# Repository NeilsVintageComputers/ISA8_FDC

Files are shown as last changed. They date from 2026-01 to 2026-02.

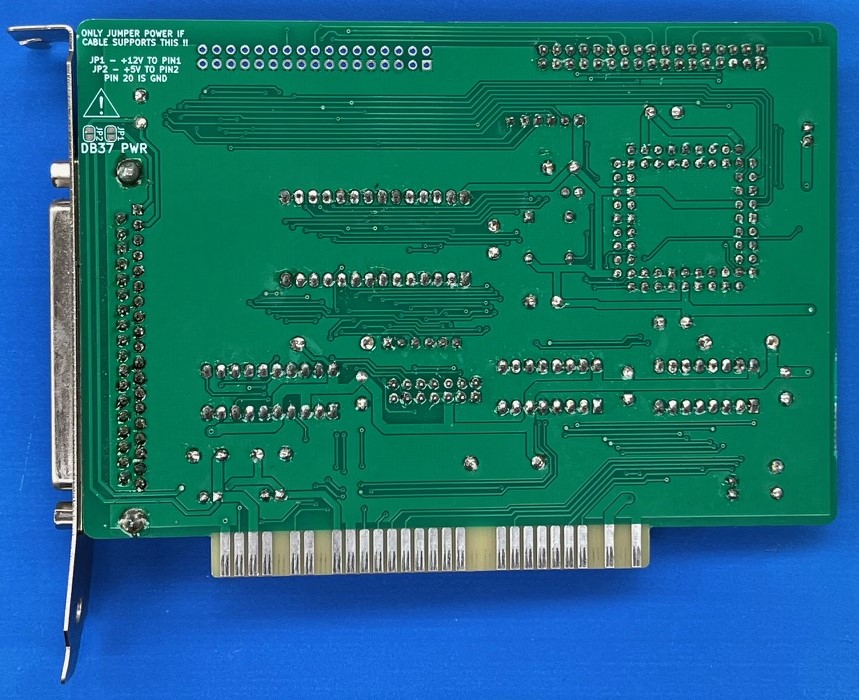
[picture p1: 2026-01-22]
ISA8_NFDCv1_4wayFDC/Photos/NFDCv1back.jpeg

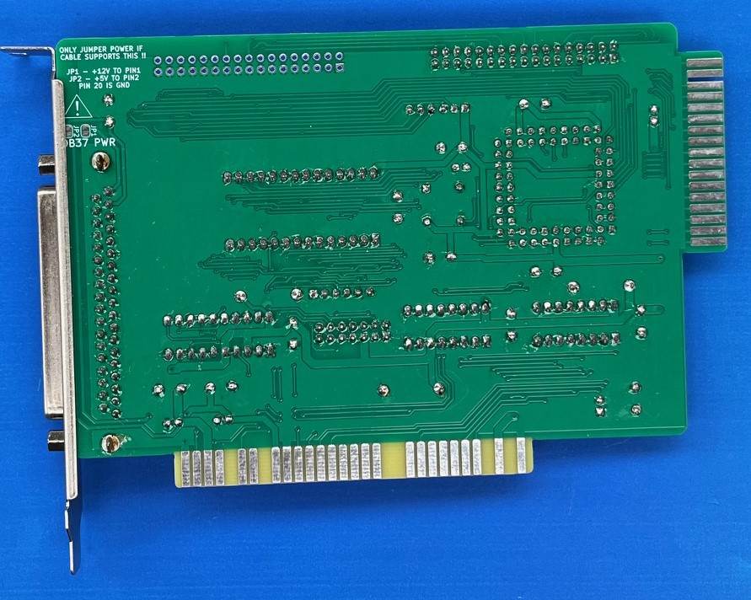
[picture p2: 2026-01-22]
ISA8_NFDCv2_4wayFDC/Photos/NFDCv2back.jpeg

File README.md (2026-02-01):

# ISA8_FDC

These FDCs are based on the Sergey Monster FDC, they use the Sergey FDC Bios V2.2, at the time of writing this was up to version 2.6 which should also work.

V1.0 is a 4-way FDC and has a external 37-pin connector option for the second pair of drives.

V2.0 supercedes V1.0, it is a 4-way FDC that has a internal PCB edge connector option for the first pair of drives and a external 37-pin connector option for the second pair of drives.

V1.0
NFDCv1

V2.0
NFDCv2

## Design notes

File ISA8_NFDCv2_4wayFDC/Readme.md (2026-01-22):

# NFDC V2.0 ISA8 FDC

This FDC is based on the Sergey Monster FDC, and uses the Sergey FDC Bios.

I have cut it down to a 4-way controller, similar to the NFDC V1.0, and added a edge connector option for the first pair of drives and a external 37-pin connector option using standard IBM pin connection that can be used for the second pair of drives.

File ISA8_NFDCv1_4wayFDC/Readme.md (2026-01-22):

# NFDC V1.0 ISA8 FDC

This FDC is based on the Sergey Monster FDC, and uses the Sergey FDC Bios.

I have cut it down to a 4-way controller and added a external 37-pin connector using standard IBM pin connection that can be used for the second pair of drives.

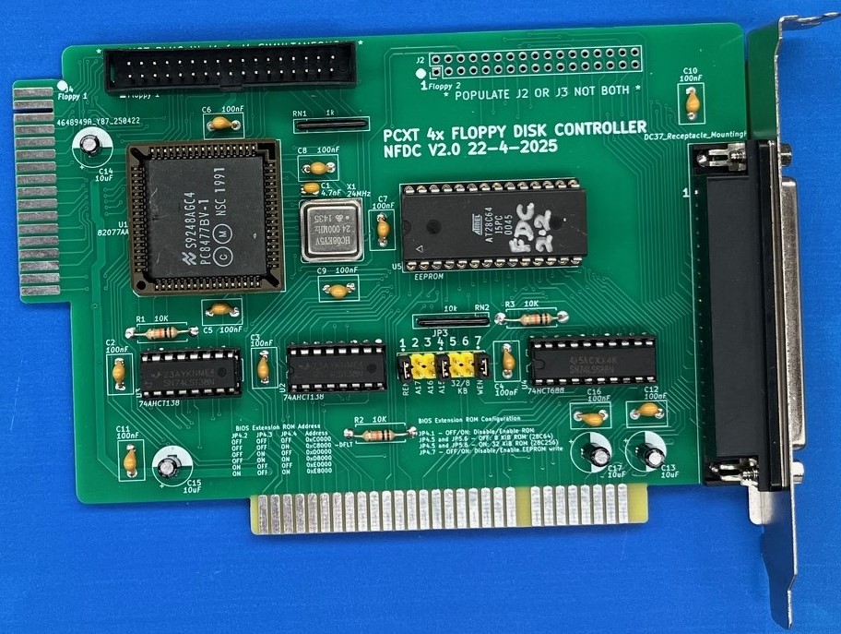
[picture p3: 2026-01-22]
ISA8_NFDCv2_4wayFDC/Photos/NFDCv2.jpeg

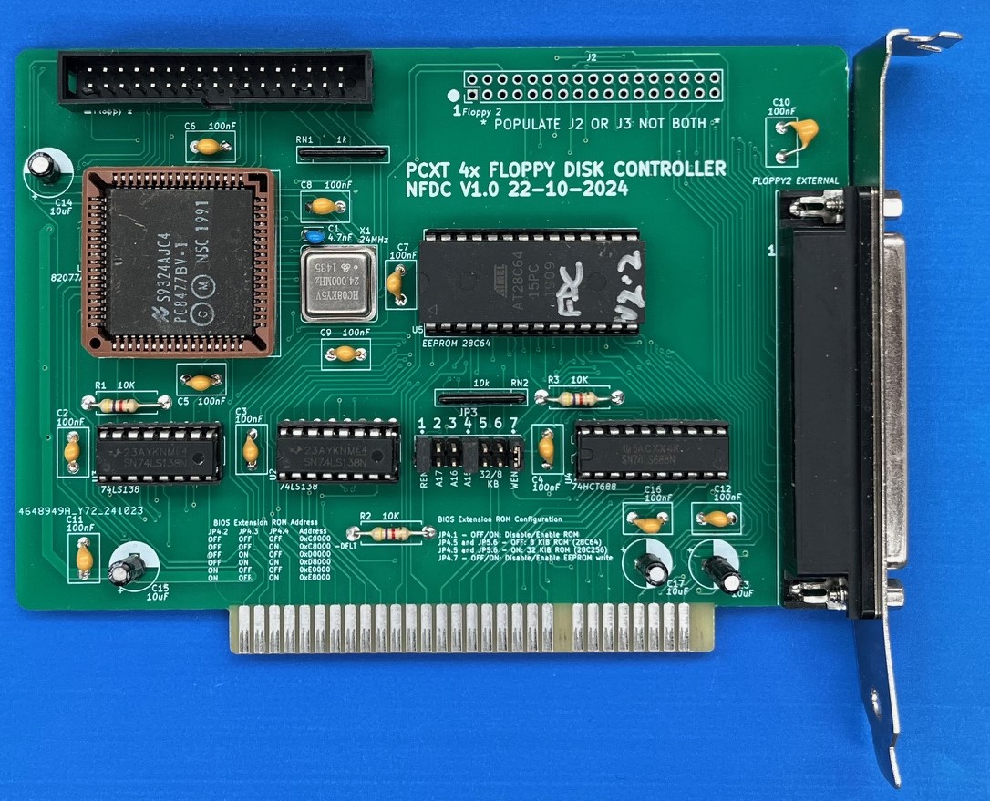
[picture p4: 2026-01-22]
ISA8_NFDCv1_4wayFDC/Photos/NFDCv1.jpeg

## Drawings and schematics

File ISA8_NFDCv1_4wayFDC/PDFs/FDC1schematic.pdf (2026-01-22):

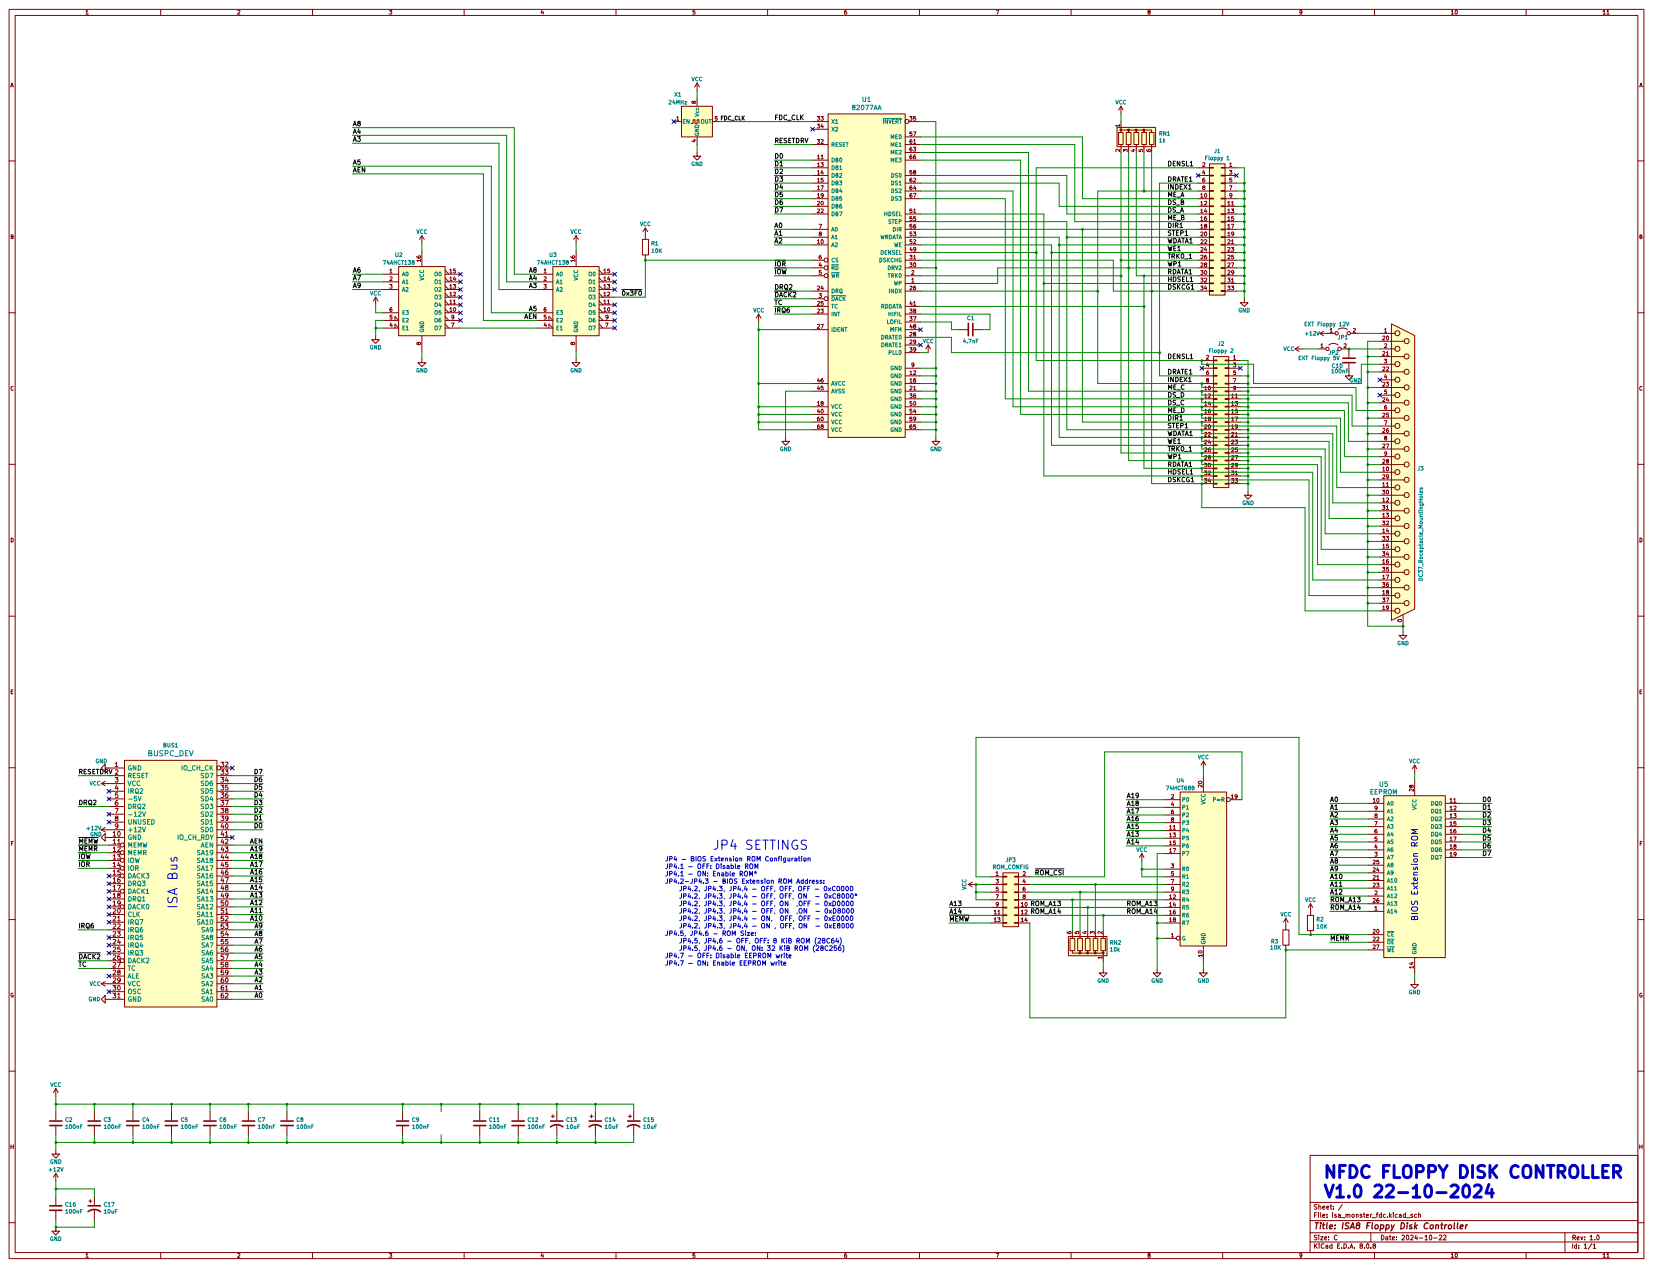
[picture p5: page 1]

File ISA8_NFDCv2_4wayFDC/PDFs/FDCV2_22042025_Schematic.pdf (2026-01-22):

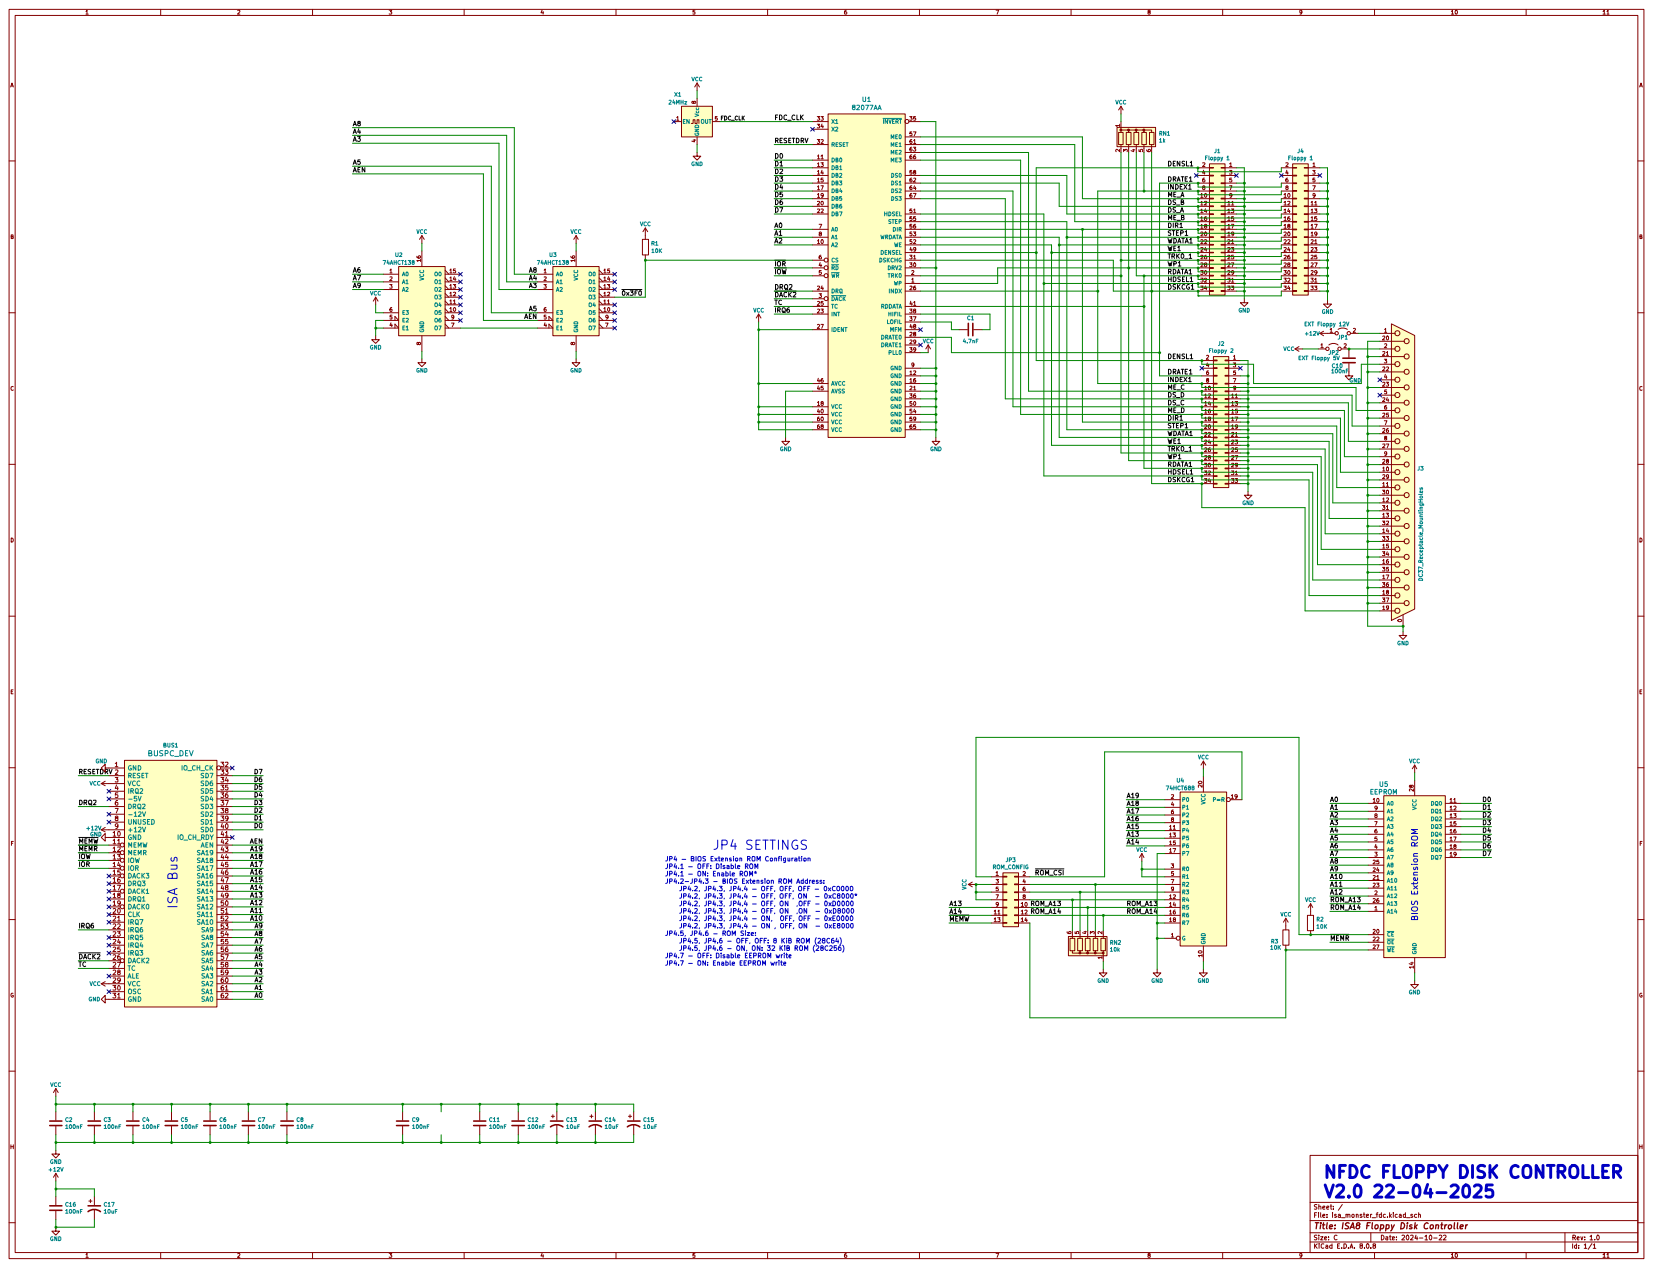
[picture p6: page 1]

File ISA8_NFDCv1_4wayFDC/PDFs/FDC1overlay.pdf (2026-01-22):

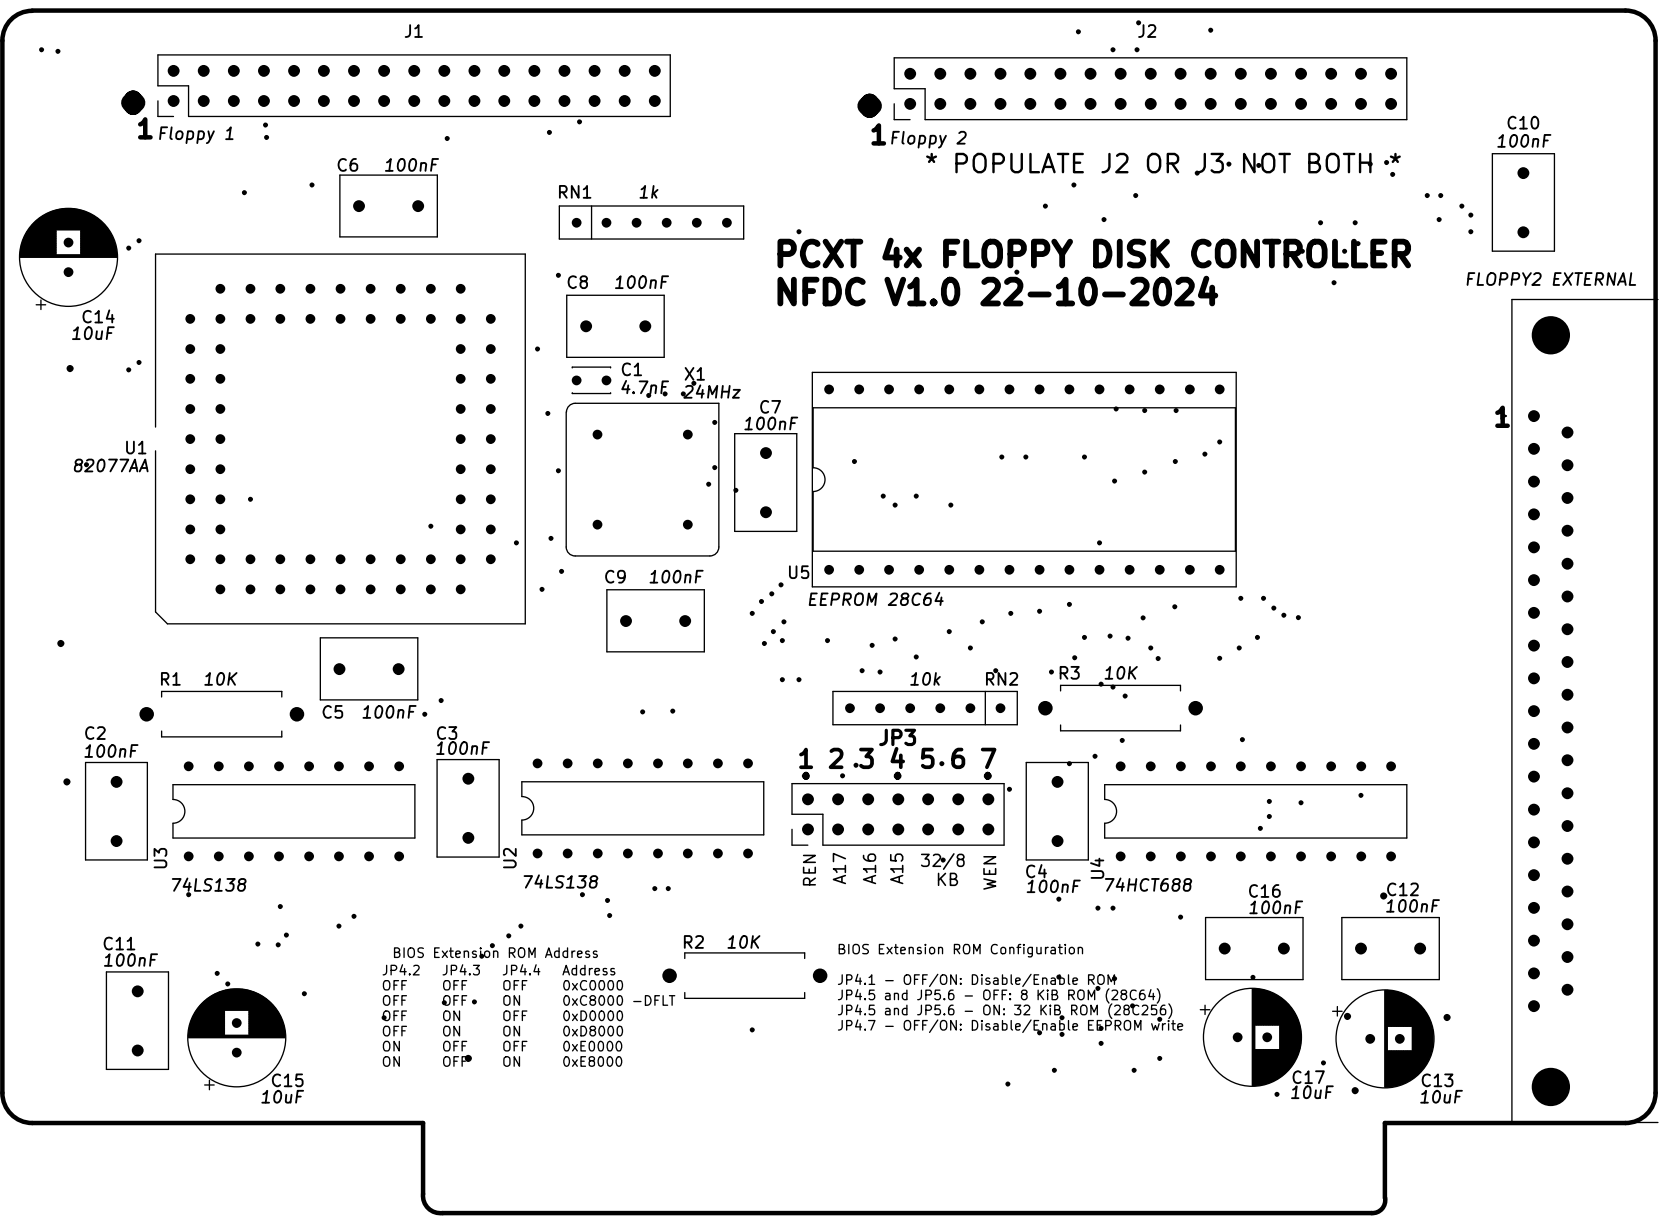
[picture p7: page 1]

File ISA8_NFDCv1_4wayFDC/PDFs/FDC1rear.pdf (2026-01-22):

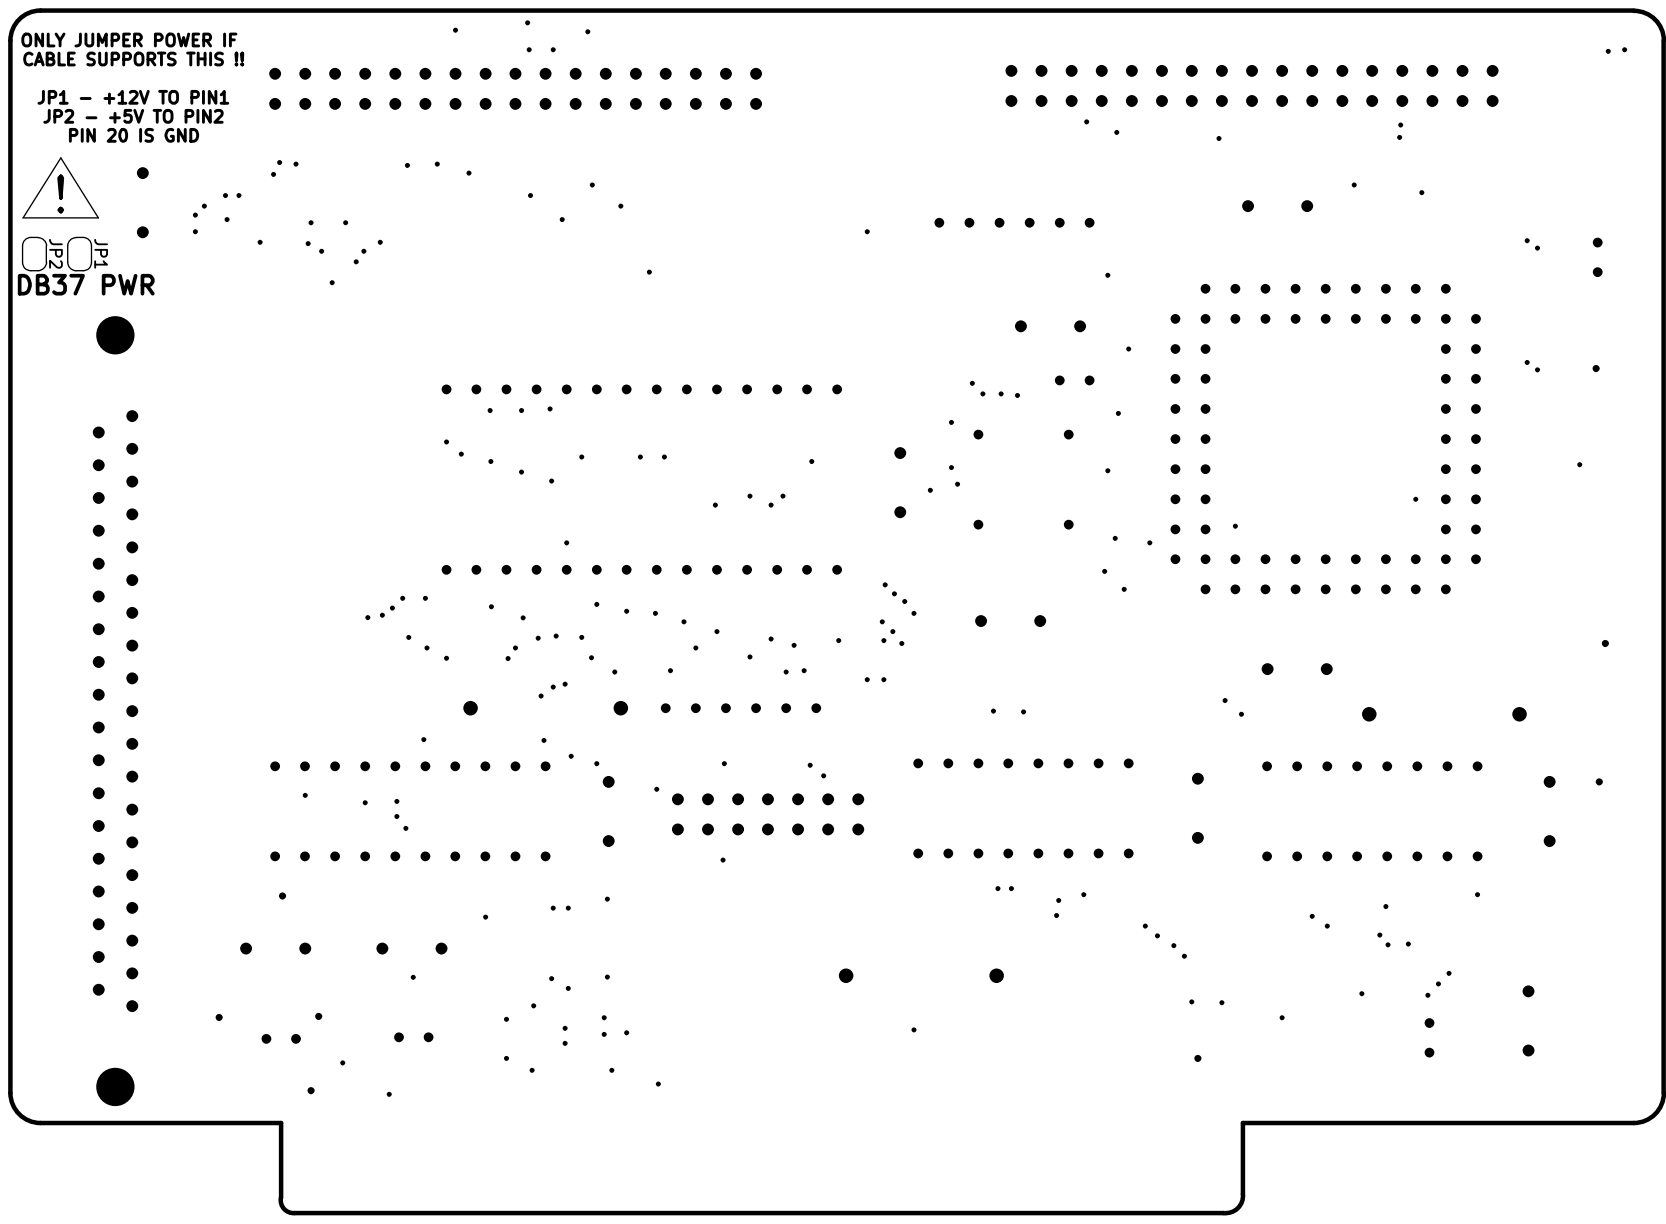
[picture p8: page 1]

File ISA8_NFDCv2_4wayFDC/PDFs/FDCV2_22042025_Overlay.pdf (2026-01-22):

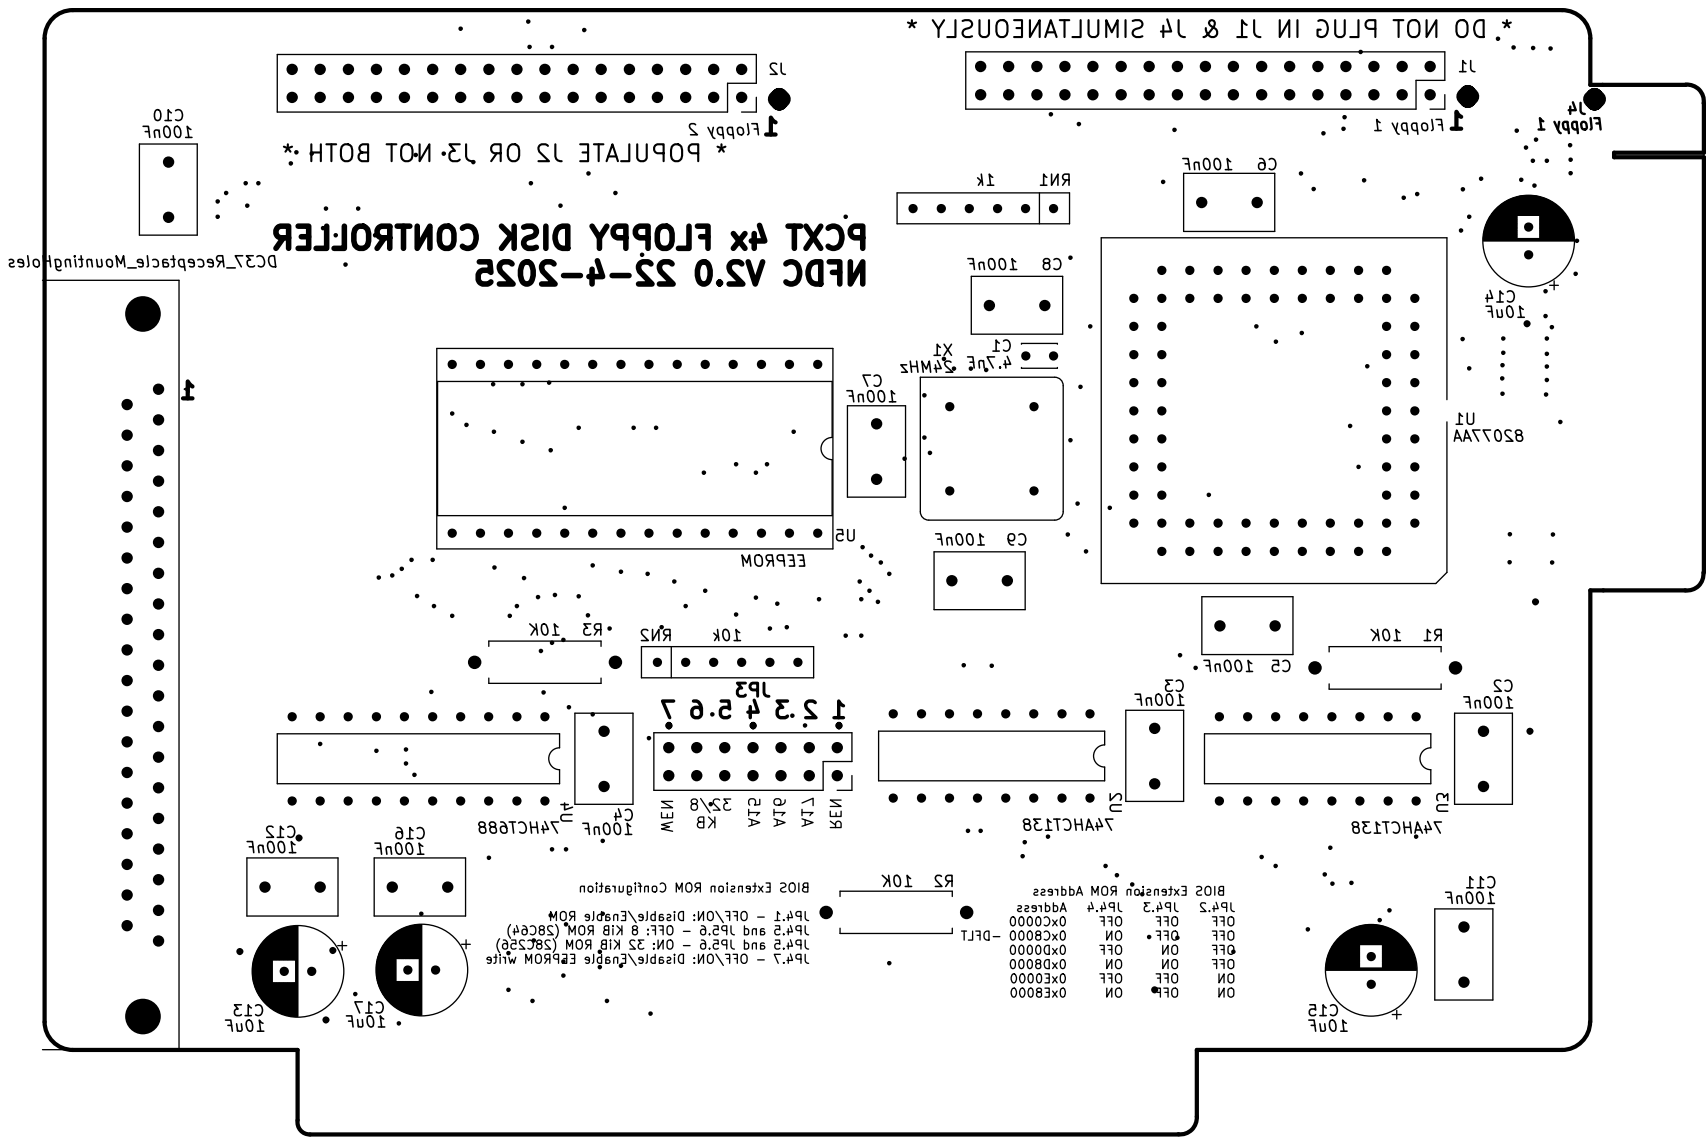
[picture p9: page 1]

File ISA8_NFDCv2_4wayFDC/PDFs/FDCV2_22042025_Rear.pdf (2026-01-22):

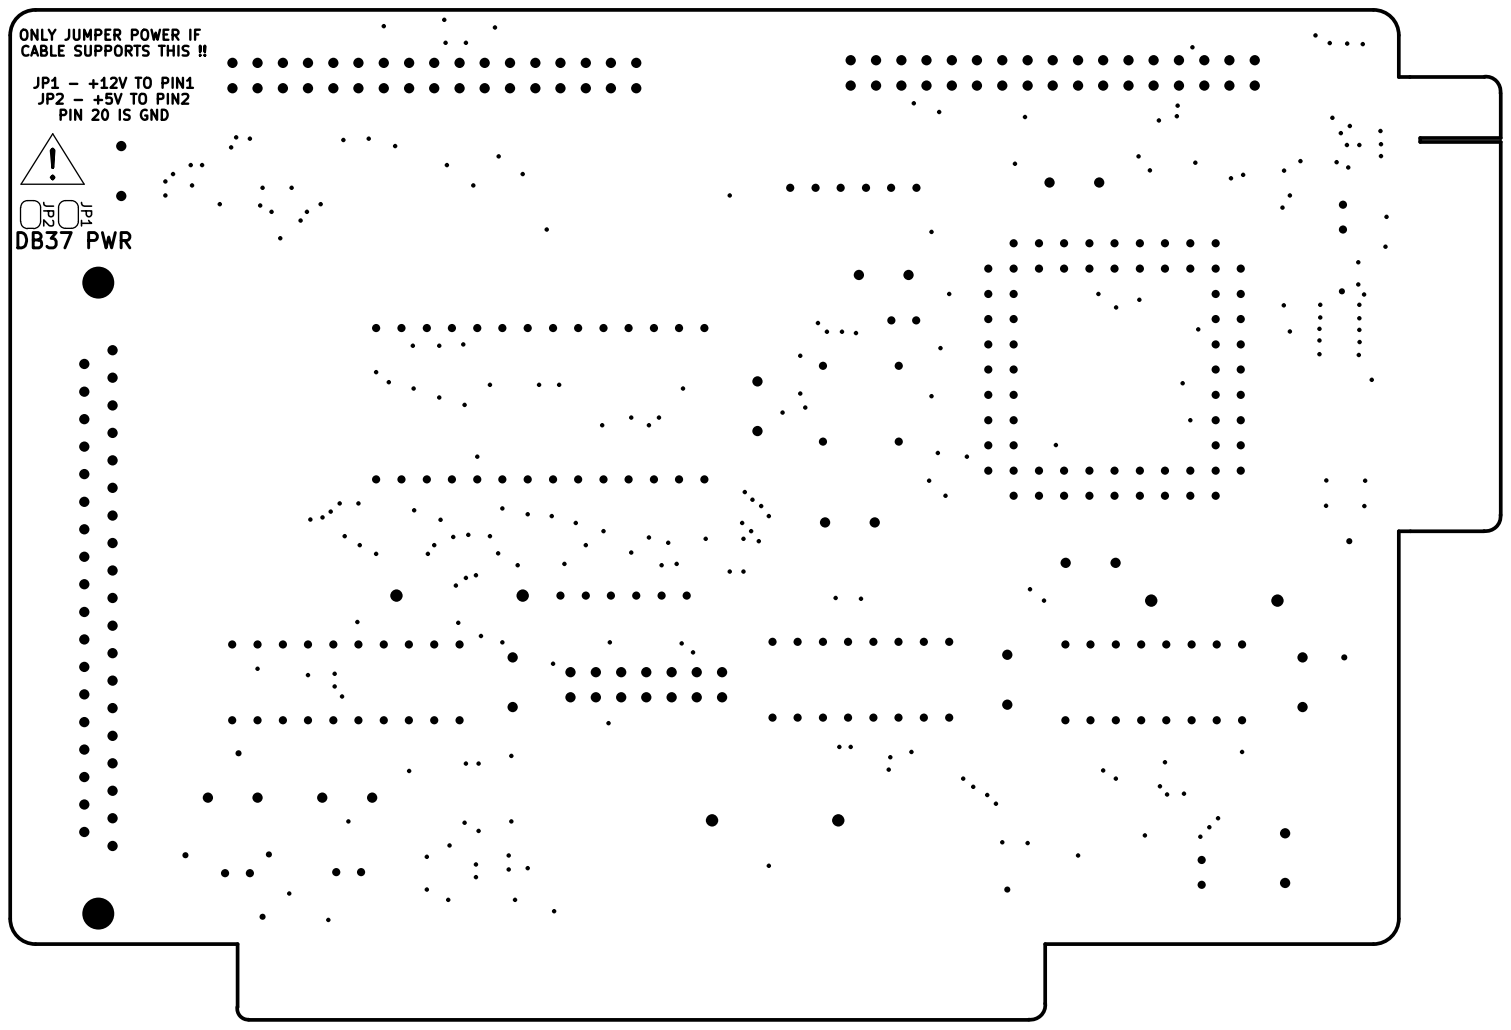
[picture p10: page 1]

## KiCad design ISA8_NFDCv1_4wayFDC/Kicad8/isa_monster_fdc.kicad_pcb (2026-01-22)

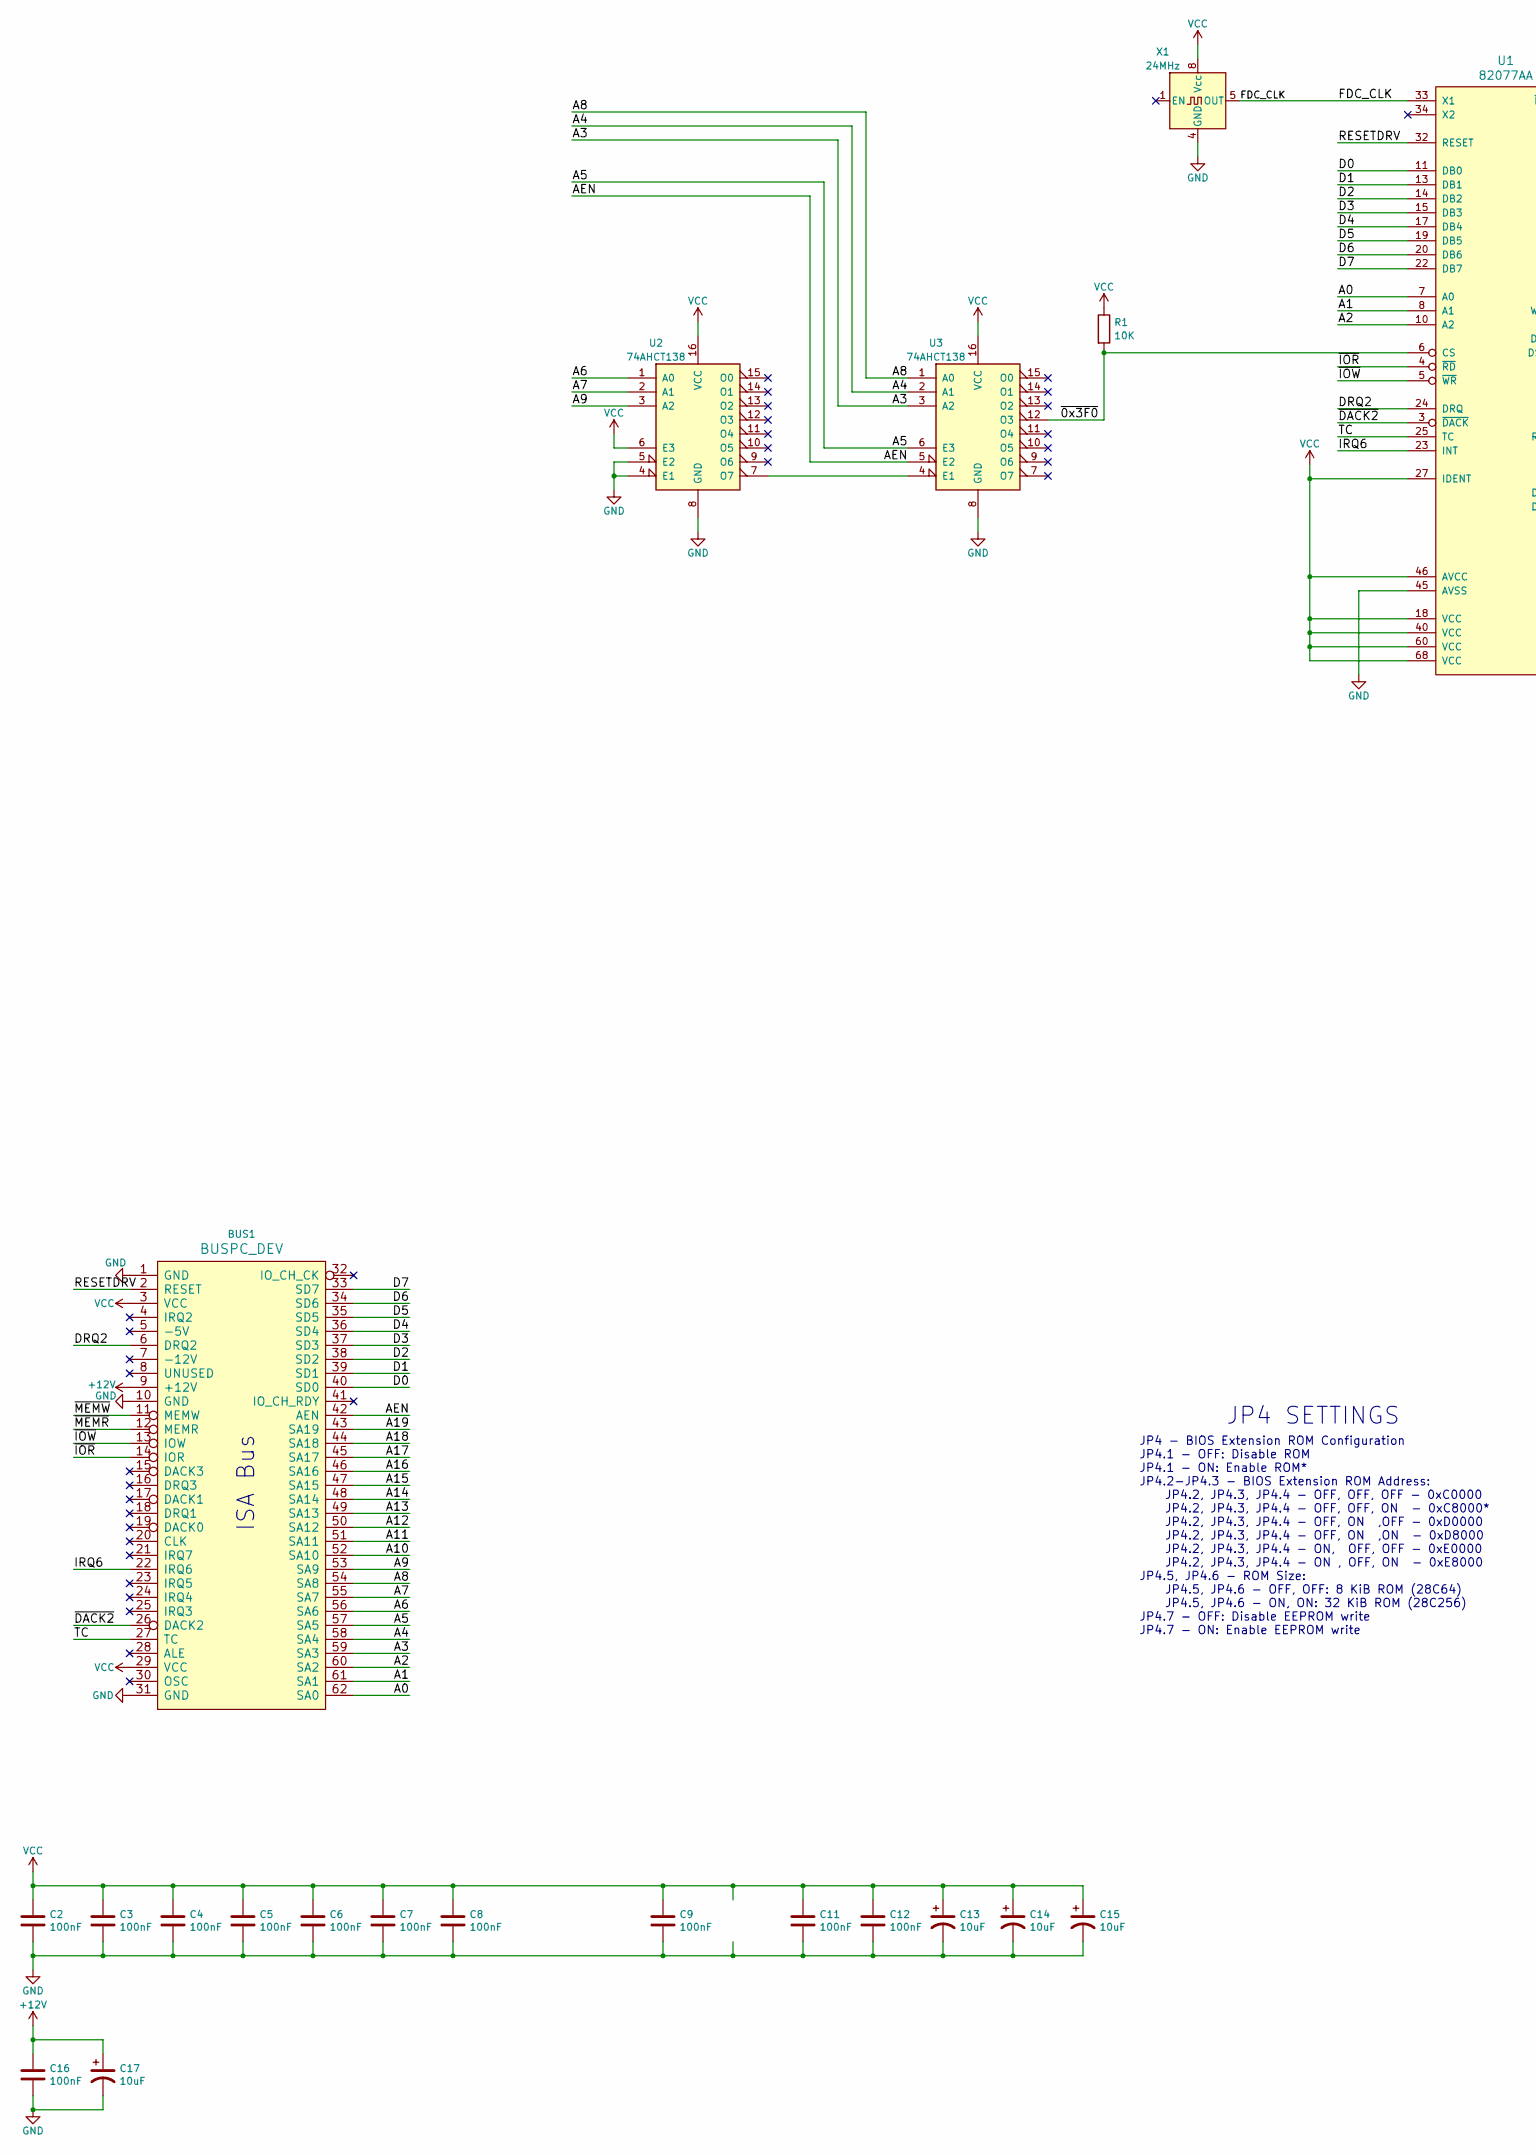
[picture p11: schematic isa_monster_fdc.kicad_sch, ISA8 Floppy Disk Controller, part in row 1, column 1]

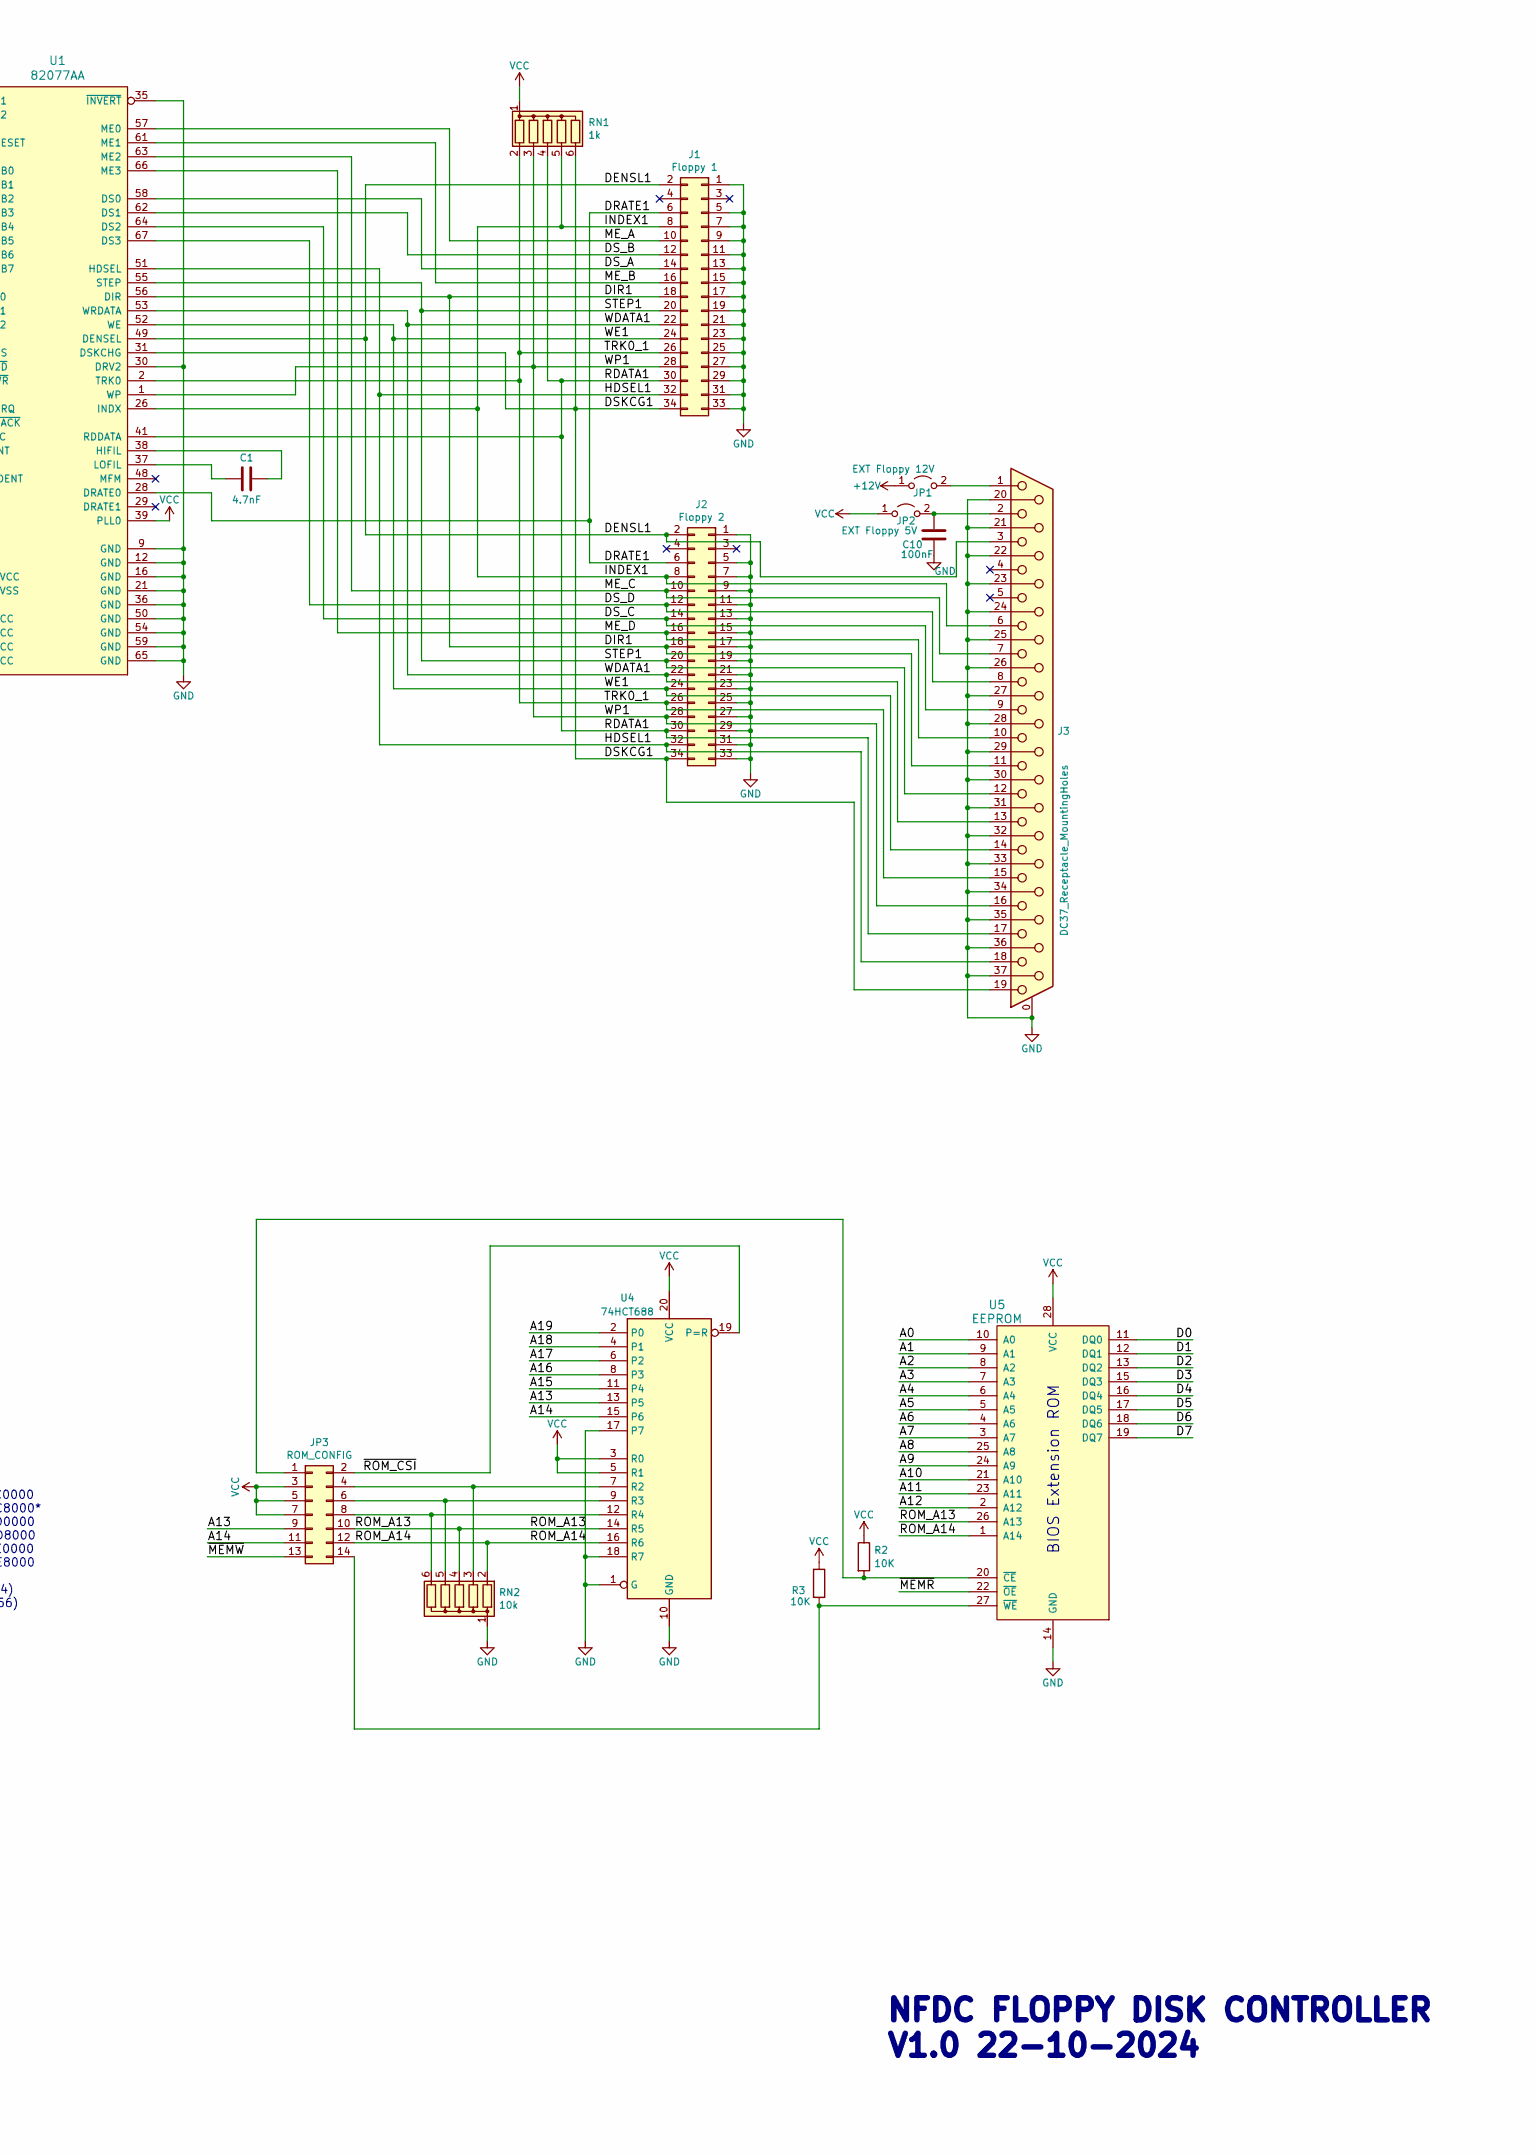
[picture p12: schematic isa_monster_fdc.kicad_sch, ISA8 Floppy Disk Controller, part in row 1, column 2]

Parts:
BUS1: BUSPC_DEV; Conn_Edge_PCB_ISA8
C1: 4.7nF; C_Disc_D3.0mm_W2.0mm_P2.50mm
C2, C3, C4, C5, C6, C7, C8, C9, C10, C11, C12, C16: 100nF; C_Disc_D8.0mm_W5.0mm_P5.00mm
C13, C14, C15, C17: 10uF; CP_Radial_D8.0mm_P2.50mm
J1: Floppy 1; PinHeader_2x17_P2.54mm_Vertical
J2: Floppy 2; PinHeader_2x17_P2.54mm_Vertical
J3: DC37_Receptacle_MountingHoles; DSUB-37_Female_Horizontal_P2.77x2.84mm_EdgePinOffset7.70mm_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
JP1: EXT Floppy 12V; SolderJumper-2_P1.3mm_Open_RoundedPad1.0x1.5mm
JP2: EXT Floppy 5V; SolderJumper-2_P1.3mm_Open_RoundedPad1.0x1.5mm
JP3: ROM_CONFIG; PinHeader_2x07_P2.54mm_Vertical
R1, R2, R3: 10K; R_Axial_DIN0411_L9.9mm_D3.6mm_P12.70mm_Horizontal
RN1: 1k; R_Array_SIP6
RN2: 10k; R_Array_SIP6
U1: 82077AA; PLCC-68_THT-Socket
U2, U3: 74AHCT138; DIP-16_W7.62mm_LongPads
U4: 74HCT688; DIP-20_W7.62mm_LongPads
U5: EEPROM; DIP-28_W15.24mm_Socket_LongPads
X1: 24MHz; Oscillator_DIP-8

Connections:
+12V: BUS1.9 (+12V), C16.1, C17.1, JP1.1 (A)
/A0: BUS1.62 (SA0), U1.7 (A0), U5.10 (A0)
/A1: BUS1.61 (SA1), U1.8 (A1), U5.9 (A1)
/A2: BUS1.60 (SA2), U1.10 (A2), U5.8 (A2)
/A3: BUS1.59 (SA3), U3.3 (A2), U5.7 (A3)
/A4: BUS1.58 (SA4), U3.2 (A1), U5.6 (A4)
/A5: BUS1.57 (SA5), U3.6 (E3), U5.5 (A5)
/A6: BUS1.56 (SA6), U2.1 (A0), U5.4 (A6)
/A7: BUS1.55 (SA7), U2.2 (A1), U5.3 (A7)
/A8: BUS1.54 (SA8), U3.1 (A0), U5.25 (A8)
/A9: BUS1.53 (SA9), U2.3 (A2), U5.24 (A9)
/A10: BUS1.52 (SA10), U5.21 (A10)
/A11: BUS1.51 (SA11), U5.23 (A11)
/A12: BUS1.50 (SA12), U5.2 (A12)
/A13: BUS1.49 (SA13), JP3.9, U4.13 (P5)
/A14: BUS1.48 (SA14), JP3.11, U4.15 (P6)
/A15: BUS1.47 (SA15), U4.11 (P4)
/A16: BUS1.46 (SA16), U4.8 (P3)
/A17: BUS1.45 (SA17), U4.6 (P2)
/A18: BUS1.44 (SA18), U4.4 (P1)
/A19: BUS1.43 (SA19), U4.2 (P0)
/AEN: BUS1.42 (AEN), U3.5 (E2)
/D0: BUS1.40 (SD0), U1.11 (DB0), U5.11 (DQ0)
/D1: BUS1.39 (SD1), U1.13 (DB1), U5.12 (DQ1)
/D2: BUS1.38 (SD2), U1.14 (DB2), U5.13 (DQ2)
/D3: BUS1.37 (SD3), U1.15 (DB3), U5.15 (DQ3)
/D4: BUS1.36 (SD4), U1.17 (DB4), U5.16 (DQ4)
/D5: BUS1.35 (SD5), U1.19 (DB5), U5.17 (DQ5)
/D6: BUS1.34 (SD6), U1.20 (DB6), U5.18 (DQ6)
/D7: BUS1.33 (SD7), U1.22 (DB7), U5.19 (DQ7)
/DENSL1: J1.2, J2.2, J3.3, U1.49 (DENSEL)
/DIR1: J1.18, J2.18, J3.11, U1.56 (DIR)
/DRATE1: J1.6, J2.6, U1.28 (DRATE0)
/DRQ2: BUS1.6 (DRQ2), U1.24 (DRQ)
/DSKCG1: J1.34, J2.34, J3.19, RN1.6 (R5), U1.31 (DSKCHG)
/DS_A: J1.14, U1.58 (DS0)
/DS_B: J1.12, U1.62 (DS1)
/DS_C: J2.14, J3.9, U1.64 (DS2)
/DS_D: J2.12, J3.8, U1.67 (DS3)
/FDC_CLK: U1.33 (X1), X1.5 (OUT)
/HDSEL1: J1.32, J2.32, J3.18, U1.51 (HDSEL)
/INDEX1: J1.8, J2.8, J3.6, RN1.5 (R4), U1.26 (INDX)
/IRQ6: BUS1.22 (IRQ6), U1.23 (INT)
/ME_A: J1.10, U1.57 (ME0)
/ME_B: J1.16, U1.61 (ME1)
/ME_C: J2.10, J3.7, U1.63 (ME2)
/ME_D: J2.16, J3.10, U1.66 (ME3)
/RDATA1: J1.30, J2.30, J3.17, RN1.4 (R3), U1.41 (RDDATA)
/RESETDRV: BUS1.2 (RESET), U1.32 (RESET)
/ROM_A13: JP3.10, RN2.4 (R3), U4.14 (R5), U5.26 (A13)
/ROM_A14: JP3.12, RN2.2 (R1), U4.16 (R6), U5.1 (A14)
/STEP1: J1.20, J2.20, J3.12, U1.55 (STEP)
/TC: BUS1.27 (TC), U1.25 (TC)
/TRK0_1: J1.26, J2.26, J3.15, RN1.2 (R1), U1.2 (TRK0)
/WDATA1: J1.22, J2.22, J3.13, U1.53 (WRDATA)
/WE1: J1.24, J2.24, J3.14, U1.52 (WE)
/WP1: J1.28, J2.28, J3.16, RN1.3 (R2), U1.1 (WP)
/~0x3F0: R1.2, U1.6 (CS), U3.12 (O3)
/~DACK2: BUS1.26 (DACK2), U1.3 (~DACK)
/~IOR: BUS1.14 (IOR), U1.4 (~RD)
/~IOW: BUS1.13 (IOW), U1.5 (~WR)
/~MEMR: BUS1.12 (MEMR), U5.22 (~OE)
/~MEMW: BUS1.11 (MEMW), JP3.13
/~ROM_CSI: JP3.2, U4.19 (P=R)
GND: BUS1.1 (GND), BUS1.10 (GND), BUS1.31 (GND), C2.2, C3.2, C4.2, C5.2, C6.2, C7.2, C8.2, C9.2, C10.2, C11.2, C12.2, C13.2, C14.2, C15.2, C16.2, C17.2, J1.1, J1.5, J1.7, J1.9, J1.11, J1.13, J1.15, J1.17, J1.19, J1.21, J1.23, J1.25, J1.27, J1.29, J1.31, J1.33, J2.1, J2.5, J2.7, J2.9, J2.11, J2.13, J2.15, J2.17, J2.19, J2.21, J2.23, J2.25, J2.27, J2.29, J2.31, J2.33, J3.0 (PAD), J3.20, J3.21, J3.22, J3.23, J3.24, J3.25, J3.26, J3.27, J3.28, J3.29, J3.30, J3.31, J3.32, J3.33, J3.34, J3.35, J3.36, J3.37, RN2.1 (common), U1.9 (GND), U1.12 (GND), U1.16 (GND), U1.21 (GND), U1.30 (DRV2), U1.35 (~INVERT), U1.36 (GND), U1.45 (AVSS), U1.50 (GND), U1.54 (GND), U1.59 (GND), U1.65 (GND), U2.4 (E1), U2.5 (E2), U2.8 (GND), U3.8 (GND), U4.1 (G), U4.10 (GND), U4.17 (P7), U4.18 (R7), U5.14 (GND), X1.4 (GND)
unnamed: J3.1, JP1.2 (B)
unnamed: C10.1, J3.2, JP2.2 (B)
unnamed: JP3.1, R2.2, U5.20 (~CE)
unnamed: JP3.4, RN2.3 (R2), U4.7 (R2)
unnamed: JP3.6, RN2.5 (R4), U4.9 (R3)
unnamed: JP3.8, RN2.6 (R5), U4.12 (R4)
unnamed: JP3.14, R3.2, U5.27 (~WE)
unnamed: C1.1, U1.38 (HIFIL)
unnamed: C1.2, U1.37 (LOFIL)
unnamed: U2.7 (O7), U3.4 (E1)
VCC: BUS1.3 (VCC), BUS1.29 (VCC), C2.1, C3.1, C4.1, C5.1, C6.1, C7.1, C8.1, C9.1, C11.1, C12.1, C13.1, C14.1, C15.1, JP2.1 (A), JP3.3, JP3.5, JP3.7, R1.1, R2.1, R3.1, RN1.1 (common), U1.18 (VCC), U1.27 (IDENT), U1.39 (PLL0), U1.40 (VCC), U1.46 (AVCC), U1.60 (VCC), U1.68 (VCC), U2.6 (E3), U2.16 (VCC), U3.16 (VCC), U4.3 (R0), U4.5 (R1), U4.20 (VCC), U5.28 (VCC), X1.8 (Vcc)

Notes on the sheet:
JP4 - BIOS Extension ROM Configuration JP4.1 - OFF: Disable ROM JP4.1 - ON: Enable ROM* JP4.2-JP4.3 - BIOS Extension ROM Address: JP4.2, JP4.3, JP4.4 - OFF, OFF, OFF - 0xC0000 JP4.2, JP4.3, JP4.4 - OFF, OFF, ON - 0xC8000* JP4.2, JP4.3, JP4.4 - OFF, ON ,OFF - 0xD0000 JP4.2, JP4.3, JP4.4 - OFF, ON ,O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
BIOS Extension ROM
NFDC FLOPPY DISK CONTROLLER V1.0 22-10-2024
JP4 SETTINGS
ISA Bus

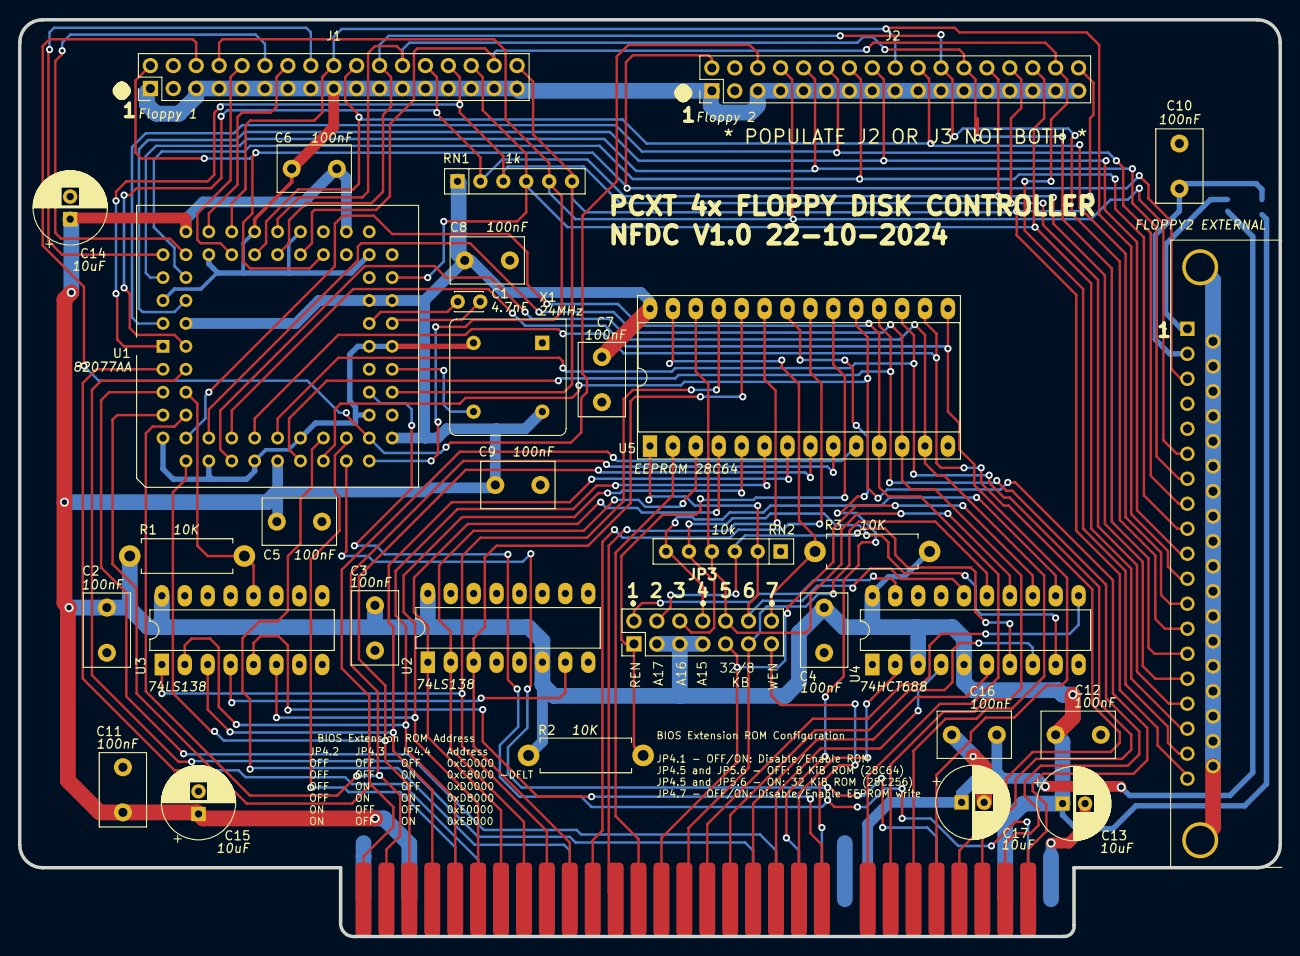
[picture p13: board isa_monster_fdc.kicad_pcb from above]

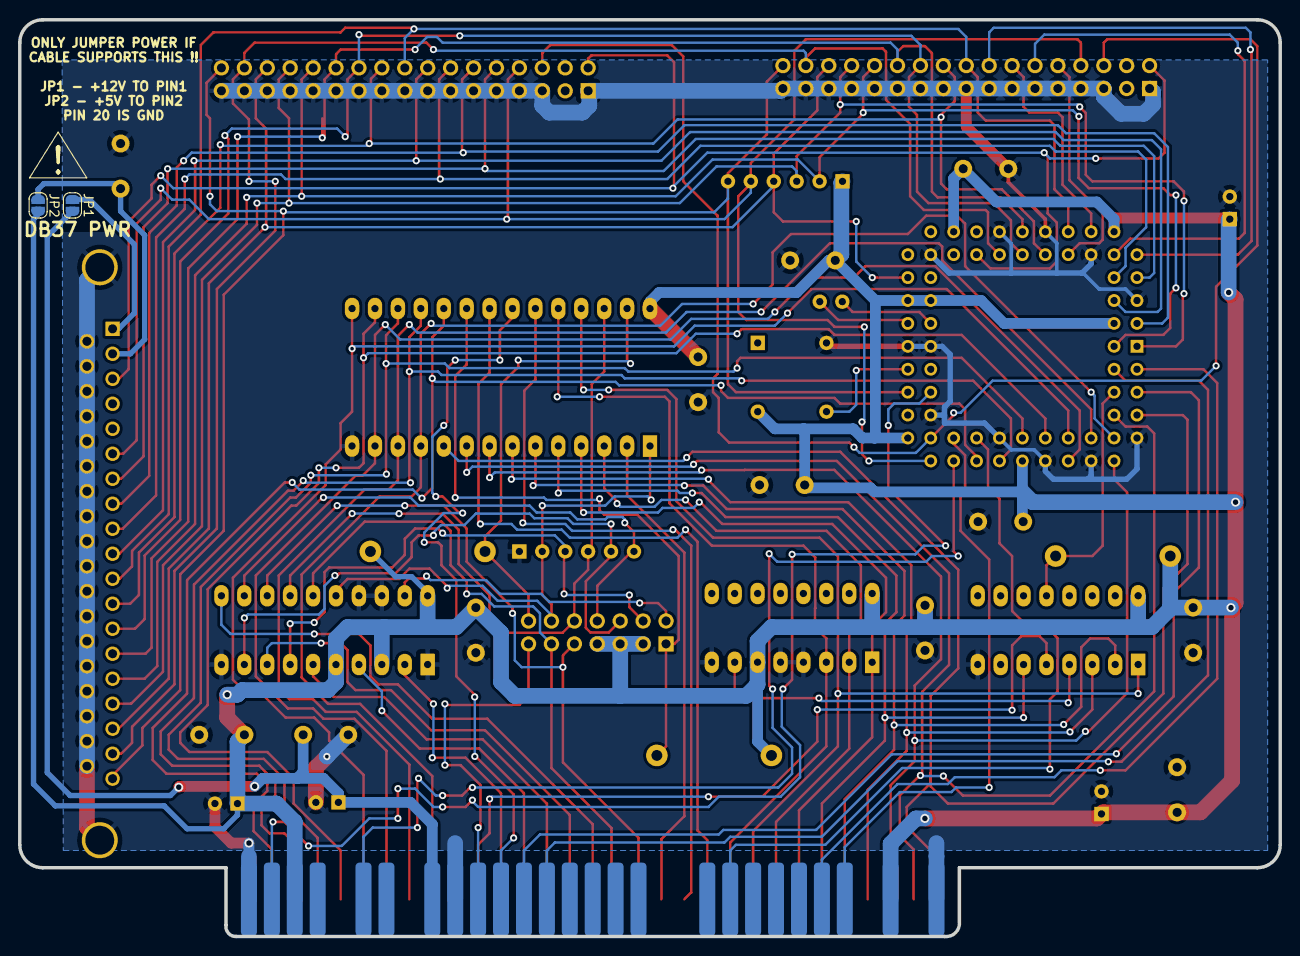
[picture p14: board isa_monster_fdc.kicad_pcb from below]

Board: 2 copper layers, 139.7 x 101.6 mm, 35 parts (2 on the bottom side), 76 nets.

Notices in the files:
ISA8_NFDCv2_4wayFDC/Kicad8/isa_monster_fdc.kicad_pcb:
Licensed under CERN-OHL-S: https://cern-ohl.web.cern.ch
